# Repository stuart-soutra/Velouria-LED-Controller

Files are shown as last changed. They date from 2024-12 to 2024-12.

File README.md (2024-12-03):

# Velouria LED Controller
## Details
The Velouria LED Controller is a 30x20mm programmable, LED controller with battery charging and protection capabilities. 
Please feel free to build and use this board for your own projects.
## Driving NeoPixels
Ideal for driving small strings of NeoPixels, testing has shown that the DC/DC convertor on the board can power up to 12 individual NeoPixels at the same time (5V, 1A max. out of DC/DC Convertor); up to 16 may be achievable.
## MCU
The controller utilises an ATTiny412 MCU that can be programmed via. the UPDI programming header on the back of the board.
One output and one input are accesible via. solder pads on the bottom of the PCB (ideal for having one single input control a string of NeoPixels via. a data output from the MCU).
## Battery Charging/Protection
The battery charging/protection circuit accepts any 3.7V Li-Ion battery.
The controller allows charging from USB Micro B connector only.
The charging circuit outputs a safe charging current of 370mA - after initial testing, it was realised that this is a slow charging rate and will be changed for Rev B.
The battery protection circuit will automatically disconnect the battery from the circuit quickly in the event of over-charging or under-charging.
## New Battery Connection Procedure
If the protection circuit trips when a new battery is connected, please follow the steps below to ensure circuit reset after connection:
 - Connect Battery
 - Short GND to Bat Negative
 - Power cycle charger
## Current Rev (Uploaded)
Rev A
## Mods Required After Rev A Testing
After initial testing, the following mods will need to be implemented in Rev B - PLEASE ADD THESE YOURSELF IF YOU PLAN ON USING THE REV A VERSION:
- Use Diodes Inc. AP9101CK6-BJTRG1 instead of current protection IC - required footprint change
- Remove filter on Vcc at input to battery charger (remove R16 and C5) - short '+5V_FUSED' to 'CHARGE_VCC'
- Change R20 for higher charge current

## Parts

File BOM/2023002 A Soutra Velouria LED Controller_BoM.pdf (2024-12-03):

# Bill of Materials for Project [2023002 A Soutra Velouria LED Controller PROJ.PrjPcb]

Source Data From: | 2023002 A Soutra Velouria LED Controller PROJ.PrjPcb
Variant: | None
Report Date: | 29/11/2023 | 11:01
soutraelectronics@gmail.com

### 14 Ryehill Gardens

Edinburgh
EH68ER
+44(0)7874693650
Designator | Manufacturer Part Number | Value | Manufacturer | Footprint | Quantity | Notes | Supplier | Supplier Part Number | Pricing | Total Cost | Supplier 1 | Supplier Part Number 1 | Pricing 1 | Total Cost | Alternative Part | Alternative Part Manufacturer | Alternative Part Supplier | Alternative Part Supplier Part Number
C1, C5, C6, C7, C8, C9 | CC0402KRX5R6BB105 | 1uF | Yageo | CAPC1005X06L | 6 | Farnell | 1458896 | 10=0.039, 100=0.023 | 0.39 | Digikey | 311-1439-1-ND | 1=0.08, 10=0.058, 50=0.034, 100=0.027 | 0.48 | 0402ZD105KAT2A | KYOCERA AVX | Farnell | 1740588 | USE JLC STOCKED PART IF AVAILABLE
C2 | GRM21BR61A476ME15K | 47uF | Murata | CAPC2012X14L | 1 | Farnell | 3790438 | 10=0.276, 100=0.207 | 2.76 | Digikey | 490-GRM21BR61A476ME15KCT-ND | 1=0.53, 10=0.353, 50=0.28, 100=0.232 | 0.53 | C2012X5R1A476M125AC | TDK | Farnell | 2211186 | USE JLC STOCKED PART IF AVAILABLE
C3 | CL31A476MQHNNNE | 47uF | Samsung | CC1206-IPC_C | 1 | Farnell | 3013519 | New Product - Undefined Lead Time | 0 | Digikey | 1276-1167-1-ND | 1=0.24, 10=0.16, 50=0.118, 100=0.096 | 0.24 | C1206C476M9PACTU | KEMET | Farnell | 1650902 | USE JLC STOCKED PART IF AVAILABLE
C4 | 0402X104M160CT | 100nF | Walsin Technologies | CAPC1005X06L | 1 | Farnell | 2524808 | 10=0.0047, 100=0.0043 | 0.047 | Digikey | 1292-0402X104M160CT-ND | 1=0.08, 10=0.023, 50=0.013, 100=0.01 | 0.08 | 885012105016 | WURTH | Farnell | 2533933 | USE JLC STOCKED PART IF AVAILABLE
C10 | CC0603KPX7R9BB472 | 4.7nF | Yageo | CC0603-DA-IPC_C | 1 | Farnell | 3764512 | 10=0.024, 100=0.014 | 0.24 | Digikey | 13-CC0603KPX7R9BB472CT-ND | 1=0.08, 10=0.036, 50=0.02, 100=0.016 | 0.08 | MC0603B472K500CT | Multicomp Pro | Farnell | 1759098 | USE JLC STOCKED PART IF AVAILABLE
D1, D3 | NSR0530HT1G | ON Semiconductor | SODFL_250X100-2L | 2 | Farnell | 2508350 | 5=0.159, 10=0.117, 100=0.0654 | 0.795 | Digikey | NSR0530HT1GOSCT-ND | 1=0.16, 10=0.11, 100=0.059 | 0.32 | PMEG3010BEA,115 | NEXPERIA | Farnell | 8737991 | USE JLC STOCKED PART IF AVAILABLE
D2 | ESDA8V2-1J | STMicroelectronics | SODFL_250X117-2L | 1 | Farnell | 2353667 | 5=0.0848, 10=0.0807, 100=0.0765 | 0.424 | Rs | 9172719 | 100=0.148 | 14.8 | USE JLC STOCKED PART IF AVAILABLE
D4 | SS12L | Multicomp Pro | SODFL370X120-2L | 1 | Farnell | 3883703 | 5=0.089, 10=0.071, 100=0.051 | 0.445 | RSX101MM-30TR | Rohm | Farnell | 3214737 | USE JLC STOCKED PART IF AVAILABLE
D5 | MP008282 | Multicomp | DIOC_0603_1706X06L | 1 | Farnell | 3796313 | 5=0.0713, 10=0.0611, 100=0.0476 | 0.3565 | LG Q396-PS-35 | AMS OSRAM GROUP | Farnell | 2575345 | USE JLC STOCKED PART IF AVAILABLE
F1 | MCCFB0603TFF/1 | Multicomp | FUSC_1608X06L | 1 | Farnell | 2849996 | 1=0.027 (GBP) | 0.027 | MP001585 | Multicomp Pro | Farnell | 3285087 | USE JLC STOCKED PART IF AVAILABLE
J1 | 105017-0001 | Molex | 1050170001_USB-MICRO-B_V | 1 | Farnell | 3500663 | 1=0.97 | 0.97 | Rs | 8486764 | 5=0.754, 75=0.67 | 3.77 | USE JLC STOCKED PART IF AVAILABLE
J2 | N/A | SMT-PAD_2x3_1-27_R0-5 | 1 | No part - solder pad only | 0
J3 | N/A | SMT-PAD_2-Pad_2X5Y2-5P | 1 | No part - solder pad only | 0
J4 | N/A | SMT-PAD_3-Pad_5X8Y6P | 1 | No part - solder pad only | 0
L1 | SRP4020TA-3R3M | Bourns | SRP4020TA-MFG | 1 | Farnell | 2434803 | 5=0.543, 50=0.52 | 2.715 | Digikey | SRP4020TA-3R3MCT-ND | 1=1.04, 10=0.879, 25=0.799, 50=0.75, 100=0.623 | 1.04 | USE JLC STOCKED PART IF AVAILABLE
Q1 | XP161A1355PR-G | Torex | SOT89-150P350X160-3L | 1 | Farnell | 3534778 | 1=0.472, 10=0.413, 100=0.294 | 0.472 | Mouser | 865-XP161A1355PR-G | 1=0.568, 10=0.453, 100=0.353 | USE JLC STOCKED PART IF AVAILABLE
Q2, Q3 | RTQ020N05FRATR | Rohm | SOT457T_95P280X100-6L | 2 | Farnell | 2769553 | 5=0.359, 10=0.286, 100=0.2 | 1.795 | RTQ020N05HZGTR | Rohm | Farnell | 3261754 | USE JLC STOCKED PART IF AVAILABLE
R1, R9, R10, R22, R26 | MC0063W06030R | 0R | Multicomp | RESC_0603_1608X06L | 5 | Farnell | 9331662 | 10=0.007, 100=0.006 | 0.07 | MCWR06X000 PTL | Multicomp Pro | Farnell | 2447743 | USE JLC STOCKED PART IF AVAILABLE
R2, R16, R23, R24, R25, R27, R28RK73B1JTTD103J | 10kR | KOA Speer | RESC_0603_1608X06L | 7 | Farnell | 4009056 | 10=0.009, 100=0.003 | 0.09 | Digikey | 2019-RK73B1JTTD103JCT-ND | 1=0.08, 10=0.012, 50=0.0078, 100=0.0064 | 0.56 | RMCF0603FT10K0 | Stackpole Electronics Inc | Digikey | RMCF0603FT10K0CT-ND | USE JLC STOCKED PART IF AVAILABLE
R11 | CRCW0805100RFKTA | 100R | Vishay Dale | RESC_0805_2013X50X30LL20T20 | 1 | Farnell | 1652906 | 10=0.06, 100=0.026 | 0.6 | Mouser | 71-CRCW0805-100 | 1=0.12, 10=0.042, 100=0.027 | 0.12 | CRCW0805100RFKEA | VISHAY | Farnell | 1469862 | USE JLC STOCKED PART IF AVAILABLE
R12 | MCWR06X3091FTL | 3.09k | Multicomp | RESC_0603_1608X06L | 1 | Farnell | 2694817 | 10=0.011, 100=0.004 | 0.11 | RK73H1JTTD3091F | KOA | Farnell | 3539881 | USE JLC STOCKED PART IF AVAILABLE
R13 | CR0603-FX-4992ELF | 49.9kR | Bourns | RESC_0603_1608X06L | 1 | Farnell | 4014374 | 1=0.0871, 25=0.0148, 50=0.0105, 100=0.0061 | 0.0871 | Digikey | 118-CR0603-FX-4992ELFCT-ND | 1=0.08, 10=0.012, 50=0.007, 100=0.006 | 0.08 | USE JLC STOCKED PART IF AVAILABLE
R14 | RK73H1JRTTD1001F | 1kR | KOA Speer | RESC_0603_1608X06L | 1 | Farnell | 3539564 | 10=0.053, 100=0.02 | 0.53 | Digikey | 2019-RK73H1JRTTD1001FCT-ND | 1=0.11, 10=0.052, 50=0.034, 100=0.0288 | 0.11 | ERJUP3J102V | PANASONIC | Farnell | 3579508 | USE JLC STOCKED PART IF AVAILABLE
R15 | CRM0805AJX-R100ELF | R100 | Bourns | RESC_0805_2013X50X30LL20T20 | 1 | Farnell | 2824733 | 10=0.218, 100=0.168 | 2.18 | Digi-Key | CRM0805AJX-R100ELFCT-ND | 1=0.49, 10=0.277, 50=0.1988, 100=0.174 | 0.49 | ERJ6BSFR10V | PANASONIC | Farnell | 1717812 | USE JLC STOCKED PART IF AVAILABLE
R17 | CRGH0805J330R | 330R | TE Connectivity | RESC_0805_2013X50X30LL20T20 | 1 | Farnell | 2331789 | 10=0.012 | 0.12 | Rs | 8075778P | 1000=0.012 | 12 | USE JLC STOCKED PART IF AVAILABLE
R18 | RC0603FR-07150RL | 150R | Yageo | RESC_0603_1608X06L | 1 | Farnell | 9238387 | 10=0.011, 100=0.006 | 0.11 | Digikey | 311-150HRCT-ND | 1=0.08, 10=0.016, 50=0.009, 100=0.008 | 0.08 | MCWR06X1500FTL | Multicomp Pro | Farnell | 2447255 | USE JLC STOCKED PART IF AVAILABLE
R19 | CRGH0805F2K7 | 2.7k | TE Connectivity | RESC_0805_2013X50X30LL20T20 | 1 | Farnell | 2332077 | 10=0.0381 | 0.381 | Mouser | 279-CRGH0805F2K7 | 1=0.096, 10=0.065, 100=0.033 | 0.096 | MC01W08051100R | Multicomp Pro | Farnell | 9332375 | USE JLC STOCKED PART IF AVAILABLE
R20 | RC0402FR-072K7L | 2.7kR | Yageo | RESC_0402_1005X40X25LL05T10 | 1 | Farnell | 9239286 | 10=0.008, 100=0.005 | 0.08 | Digikey | 311-2.70KLRCT-ND | 1=0.08, 10=0.012, 50=0.007, 100=0.006 | 0.08 | MCSR04X2701FTL | Multicomp Pro | Farnell | 2074044 | USE JLC STOCKED PART IF AVAILABLE
SW1 | N/A | SMT-PAD_2-Pad_2X5Y2-5P | 1 | No part - solder pad only | 0
U1 | ATTINY412-SSNR | Microchip | SOIC127P600X200-8L | 1 | Farnell | 3131843 | 1=0.469, 25=0.429, 100=0.39 | 0.469 | Digikey | ATTINY412-SSNRCT-ND | 1=0.48, 25=0.437, 0.388 | 0.48 | USE JLC STOCKED PART IF AVAILABLE
U2 | MCP1650S-E/MS | Microchip | MSOP-MS8_L | 1 | Farnell | 1863920 | 1=1.548 | 1.548 | Digikey | MCP1650S-E/MS-ND | 1=1.54, 25=1.288, 100=1.228 | 1.54 | USE JLC STOCKED PART IF AVAILABLE
U3 | LTC4065EDC#TRMPBF | Analog Devices / Linear Technology | DFN_0P200X200X85_HS-7L | 1 | Farnell | 4027894 | 1=3.14, 10=2.81, 25=2.67, 100=2.31 | 3.14 | Digikey | 505-LTC4065EDC#TRMPBFCT-ND | 1=2.94, 10=2.64, 25=2.495, 100=2.162 | 2.94 | USE JLC STOCKED PART IF AVAILABLE
U4 | AP9101CK-AHTRG1 | Diodes | SOT25_95P285X140-5L | 1 | Farnell | 3483011 | 5=0.318, 10=0.231, 100=0.165 | 1.59 | DigiKey | AP9101CK-AHTRG1DICT-ND | 1=0.36, 10=0.28, 100=0.169 | 0.36 | USE JLC STOCKED PART IF AVAILABLE
U5 | AP22802AW5-7 | Diodes | SOT25_95P285X140-5L | 1 | Farnell | 3482850 | 5=0.152, 10=0.133, 100=0.11 | 0.76 | Digikey | AP22802AW5-7DICT-ND | 1=0.37, 10=0.277, 25=0.25, 100=0.173 | 0.37 | USE JLC STOCKED PART IF AVAILABLE
U6 | AP331AWRG-7 | Diodes | SOT25_95P285X140-5L | 1 | Farnell | 3373792 | 5=0.259, 10=0.16, 100=0.098 | 1.295 | Digikey | AP331AWRGDICT-ND | 1=0.38, 10=0.28, 25=0.256, 100=0.176 | 0.38 | USE JLC STOCKED PART IF AVAILABLE
Note: | - All prices in GBP | Total Number of Items: | 52

TOTAL MAX COST PER BOARD
(Primary Supplier Only): | 24.5966
- Supplier minimum order amount assumed if number of components is less
- PLEASE CHOOSE CHEAPEST AVAILABLE COMPONENT CHOICE WHEN SOURCING
Primary Supplier | Secondary Supplier | Alternative Part Details | JLC Stock Accepted?

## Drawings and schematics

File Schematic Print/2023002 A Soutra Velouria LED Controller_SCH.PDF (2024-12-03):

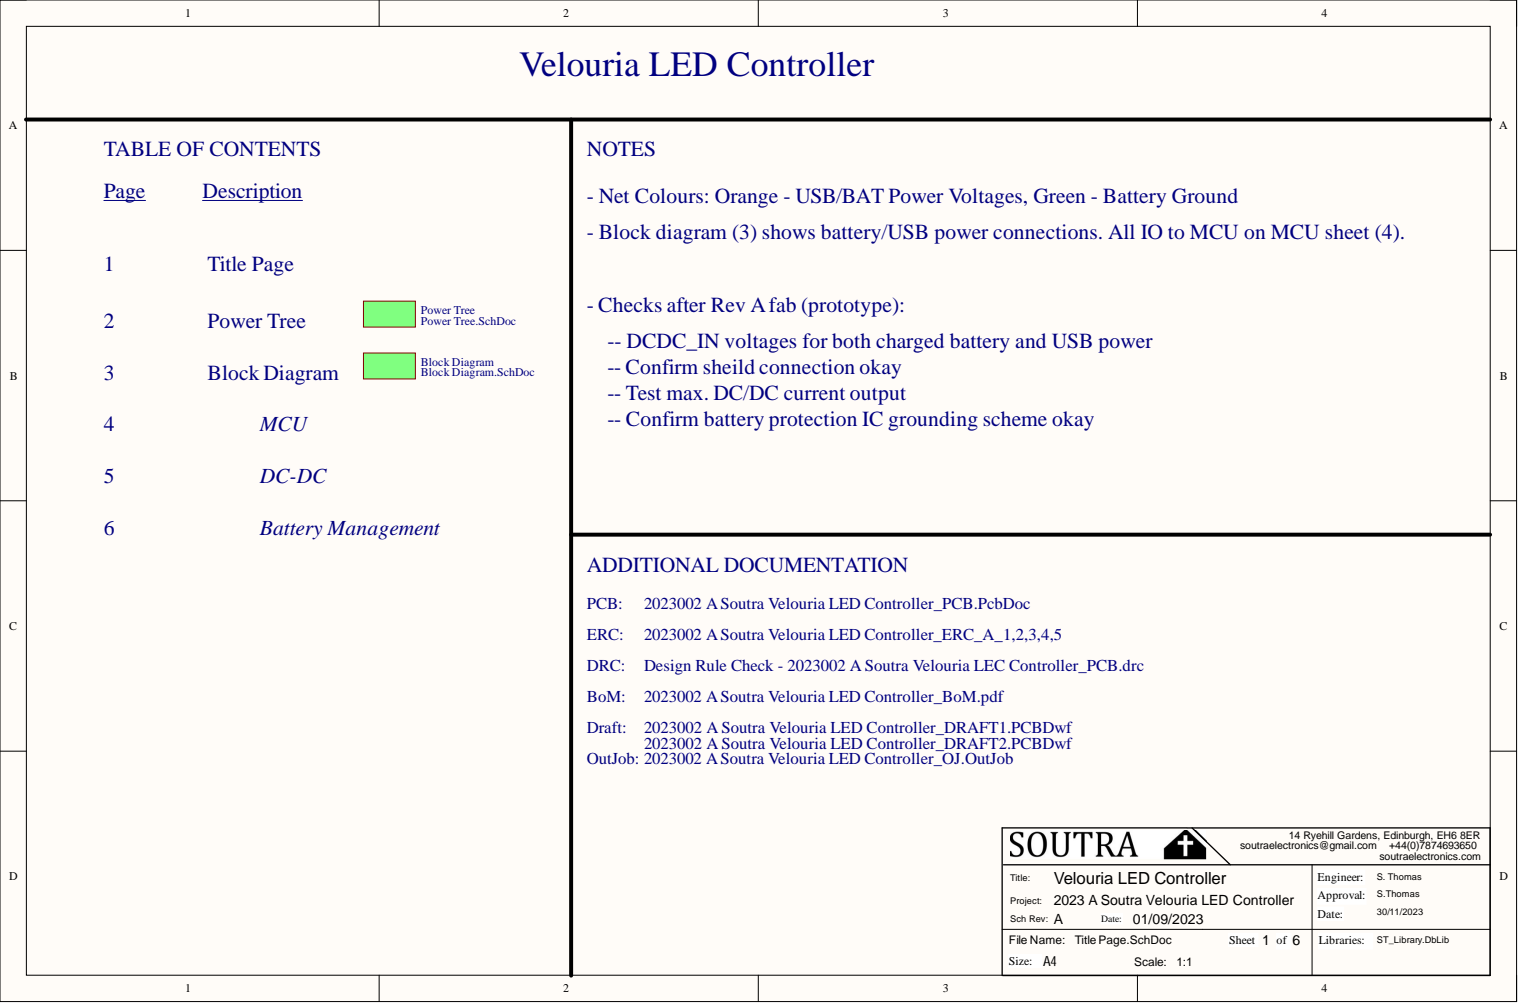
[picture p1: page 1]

- Net Colours: Orange - USB/BAT Power Voltages, Green - Battery Ground
- Block diagram (3) shows battery/USB power connections. All IO to MCU on MCU sheet (4).

- Checks after Rev Afab (prototype):
-- DCDC_IN voltages for both charged battery and USB power
-- Confirm sheild connection okay
-- Test max. DC/DC current output
-- Confirm battery protection IC grounding scheme okay

Power Tree Power Tree.SchDoc

Block Diagram Block Diagram.SchDoc

Design Rule Check - 2023002 A Soutra Velouria LEC Controller_PCB.drc

2023002 A Soutra Velouria LED Controller_BoM.pdf

2023002 A Soutra Velouria LED Controller_DRAFT1.PCBDwf
2023002 A Soutra Velouria LED Controller_DRAFT2.PCBDwf
2023002 A Soutra Velouria LED Controller_OJ.OutJob

Velouria LED Controller
2023 A Soutra Velouria LED Controller

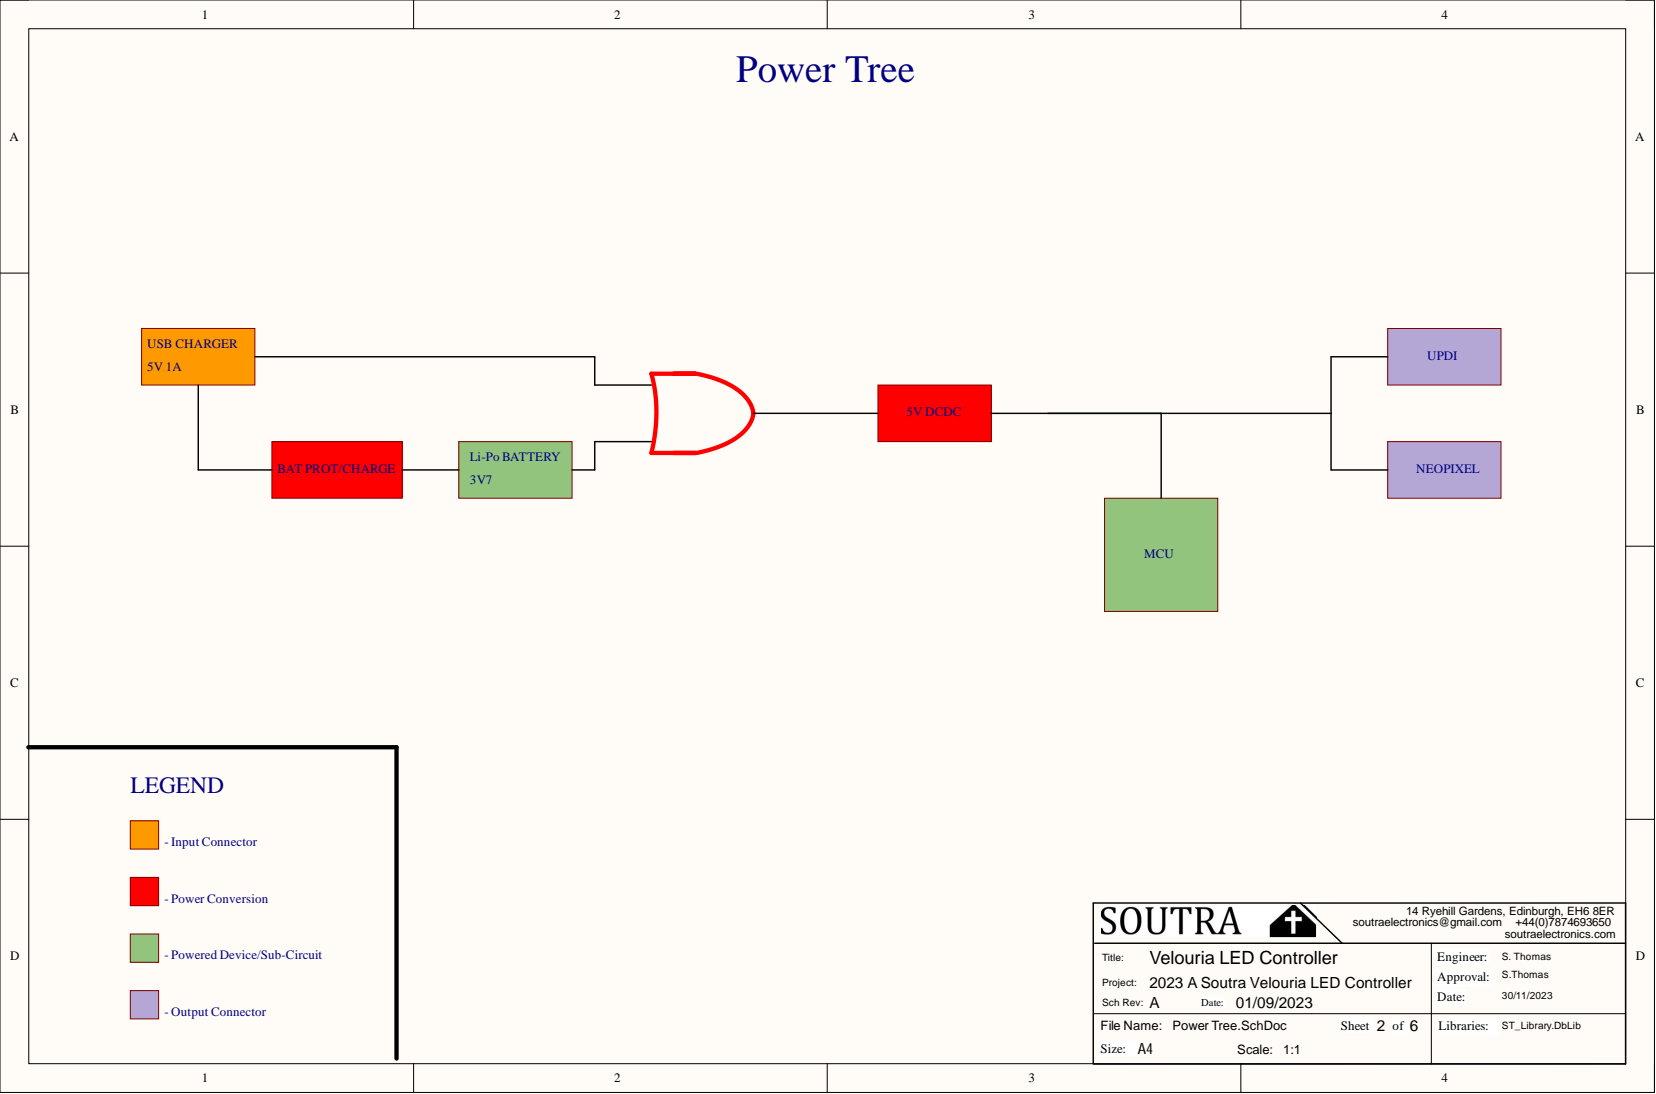
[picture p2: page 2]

- Powered Device/Sub-Circuit

Velouria LED Controller
2023 A Soutra Velouria LED Controller

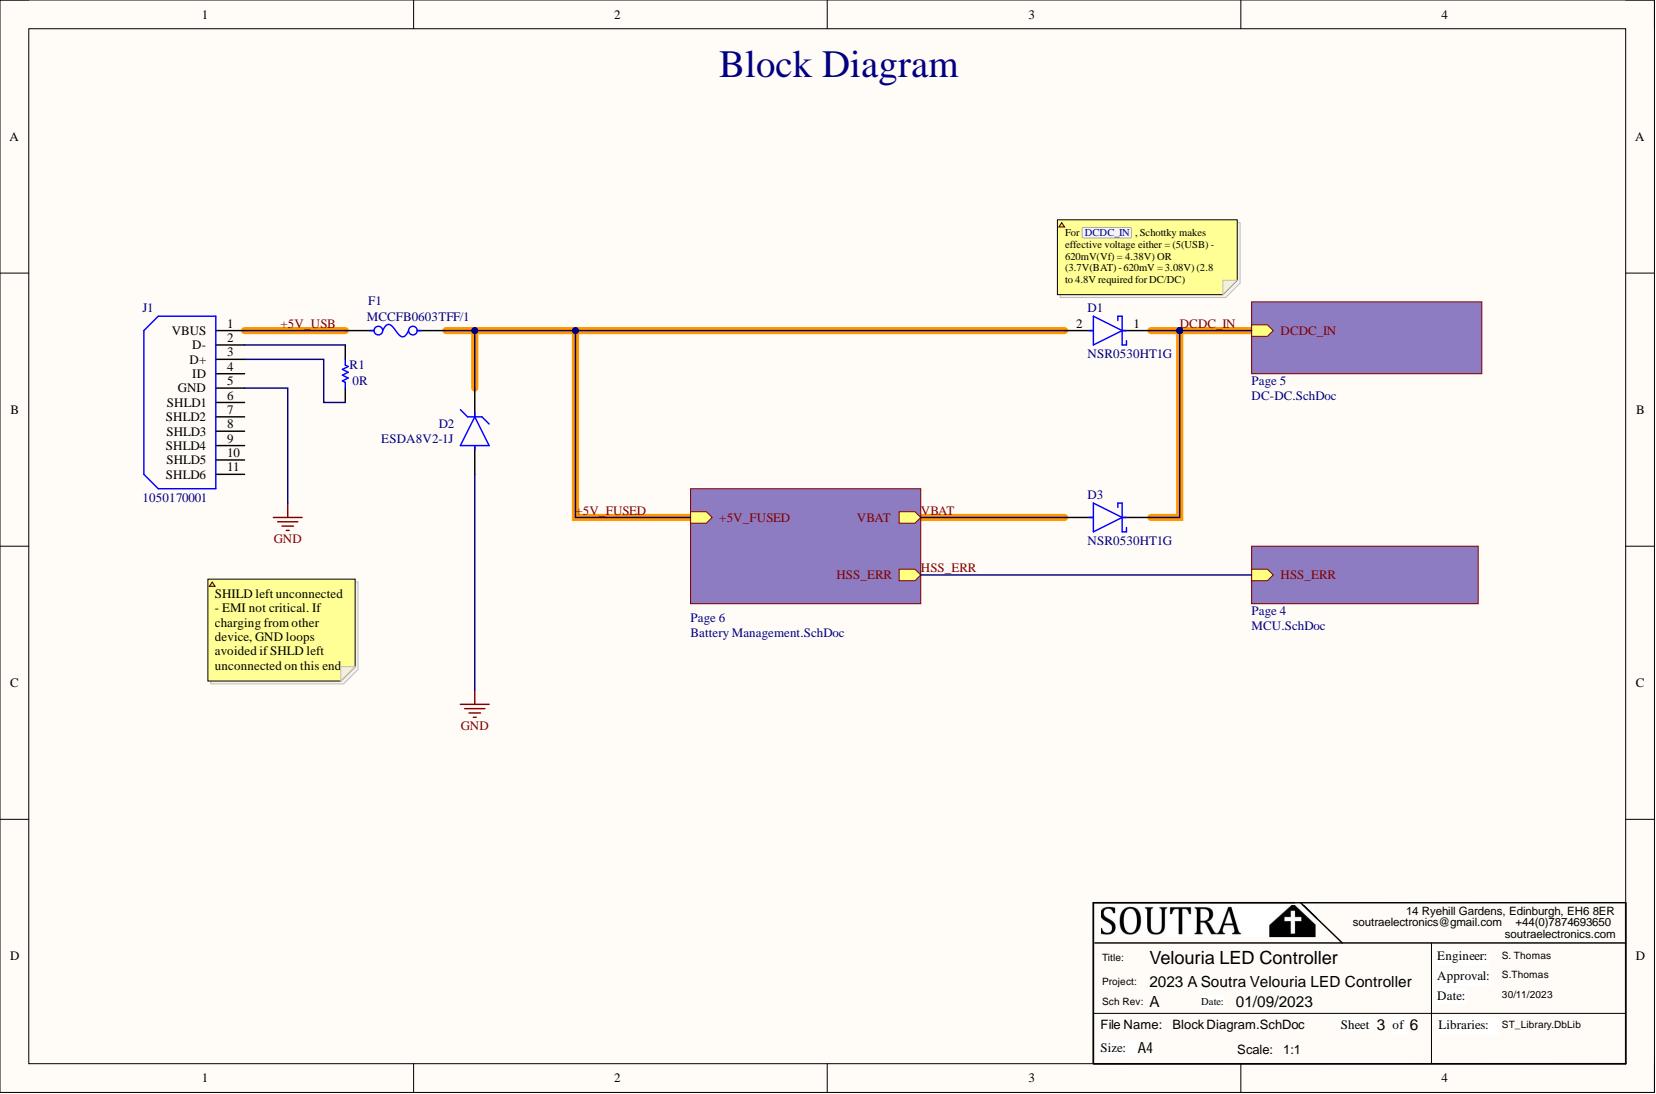
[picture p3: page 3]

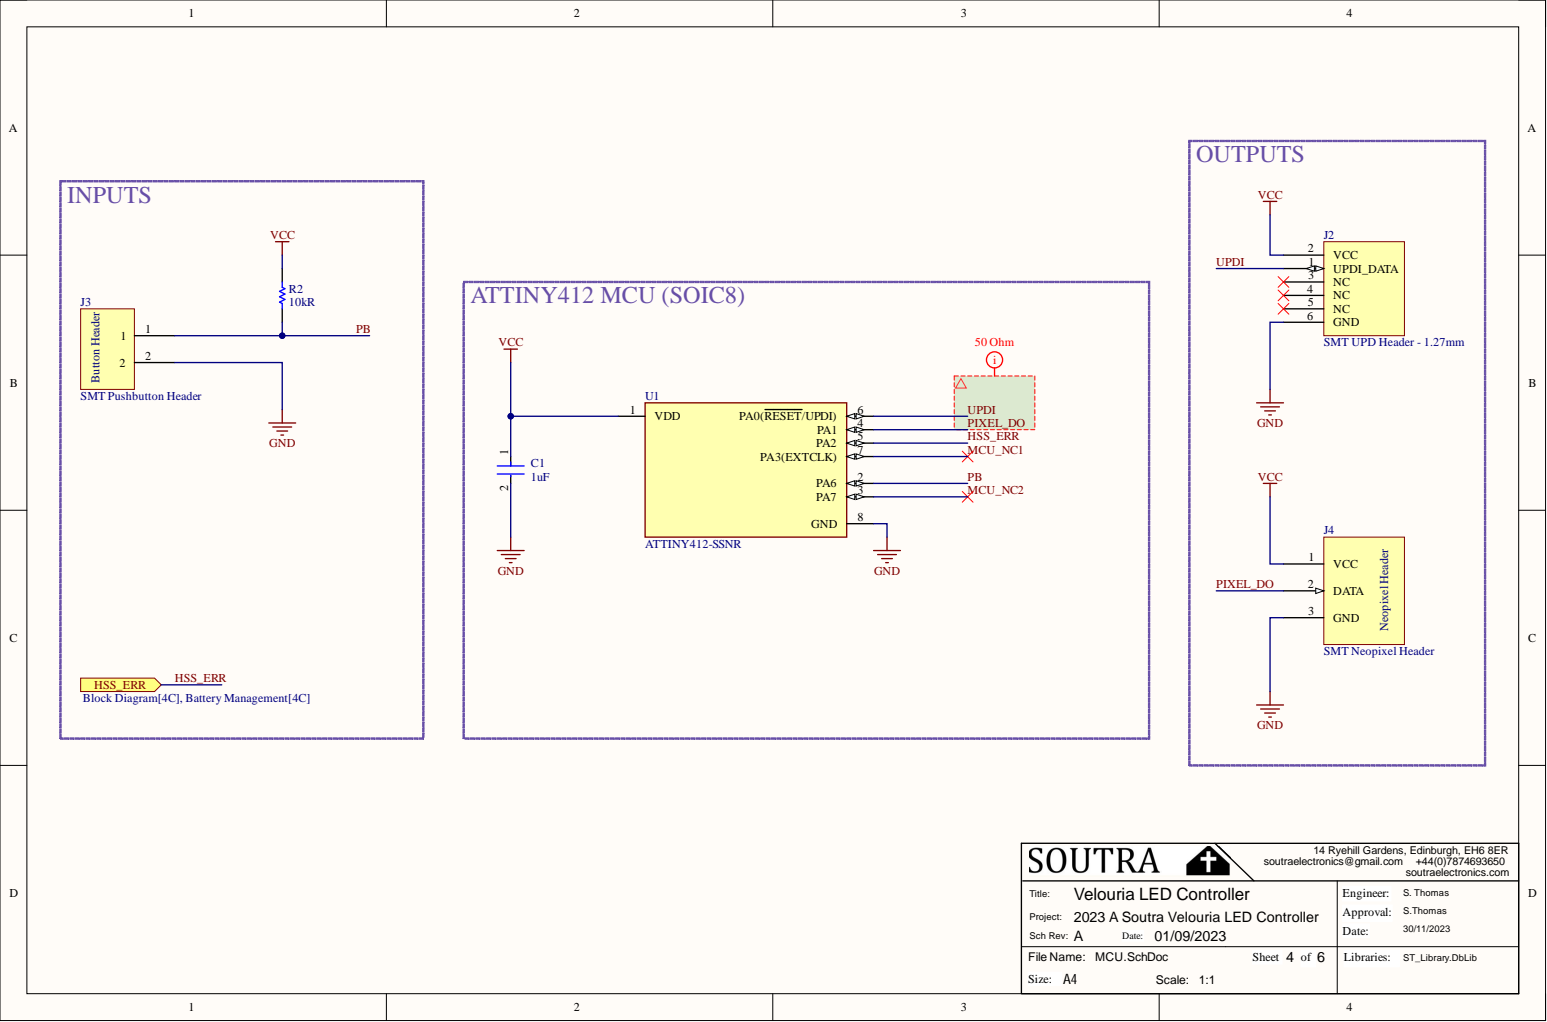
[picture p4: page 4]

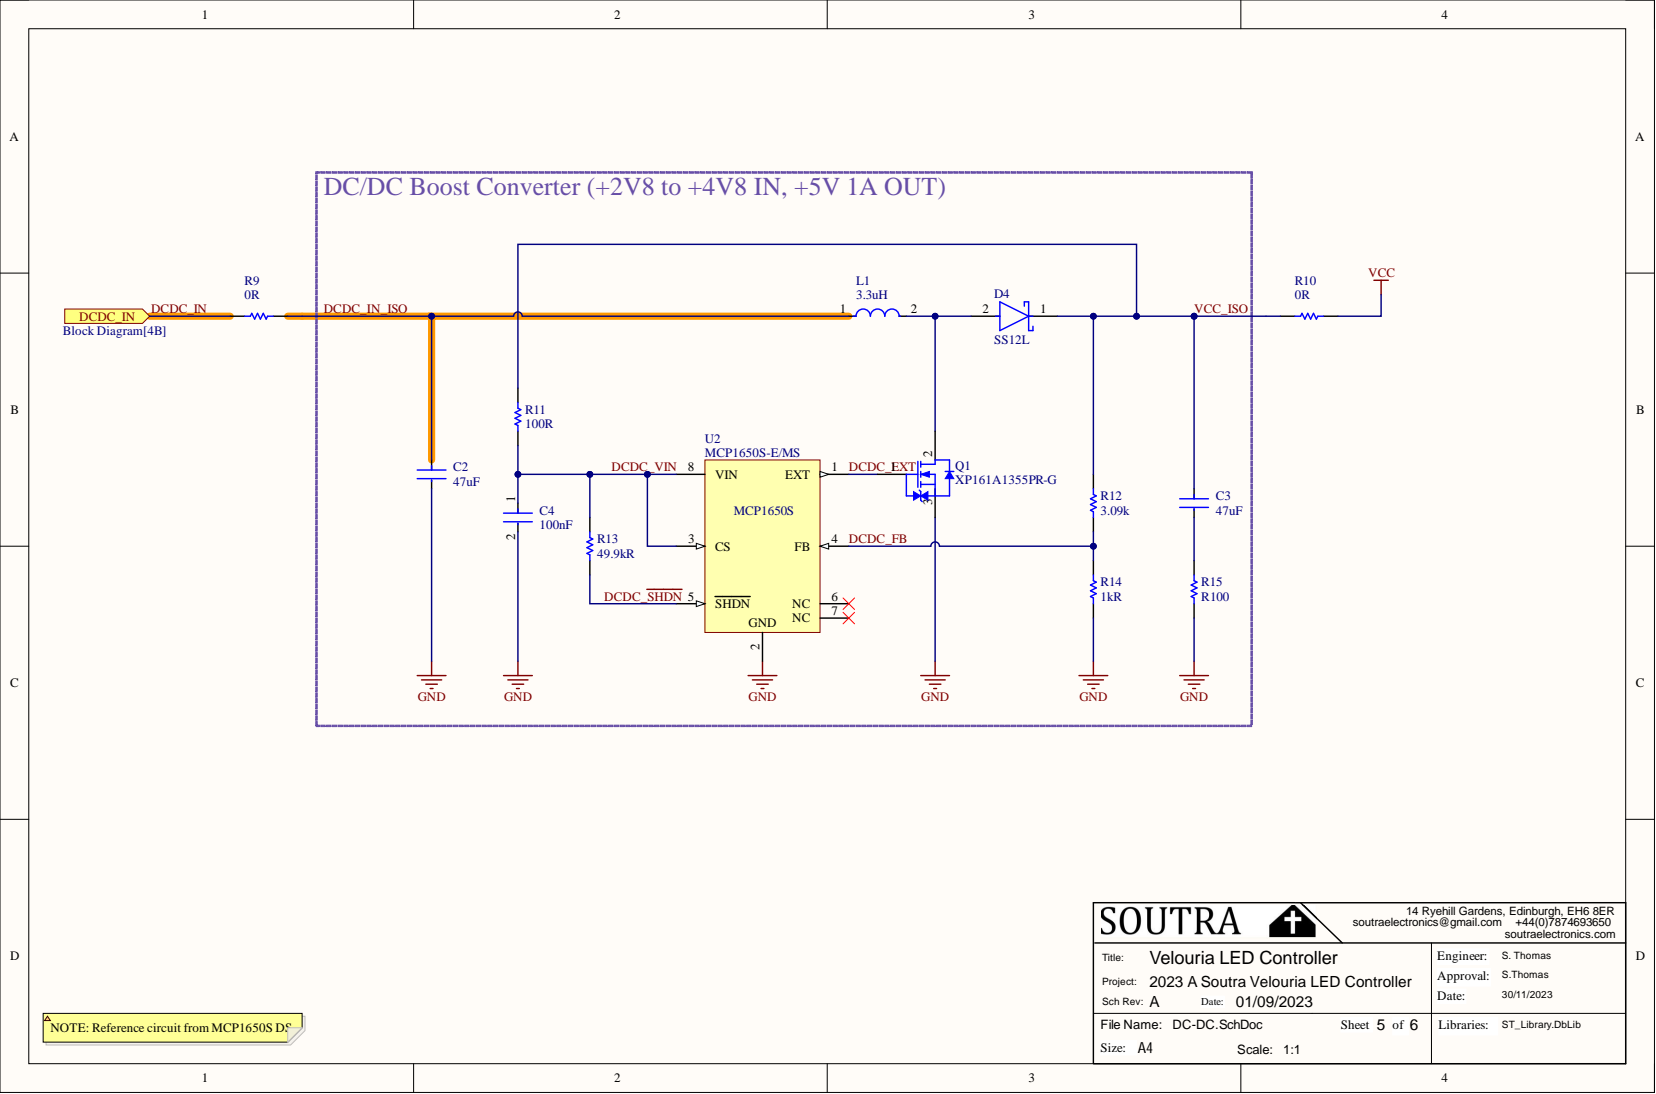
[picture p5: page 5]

DC/DC Boost Converter (+2V8 to +4V8 IN, +5V 1A OUT)

V IN 8 | V IN E X T MCP1 6 5 0 S CS FB SH D N N C N C G N D | 1

3 | 4 DCDC_ FB

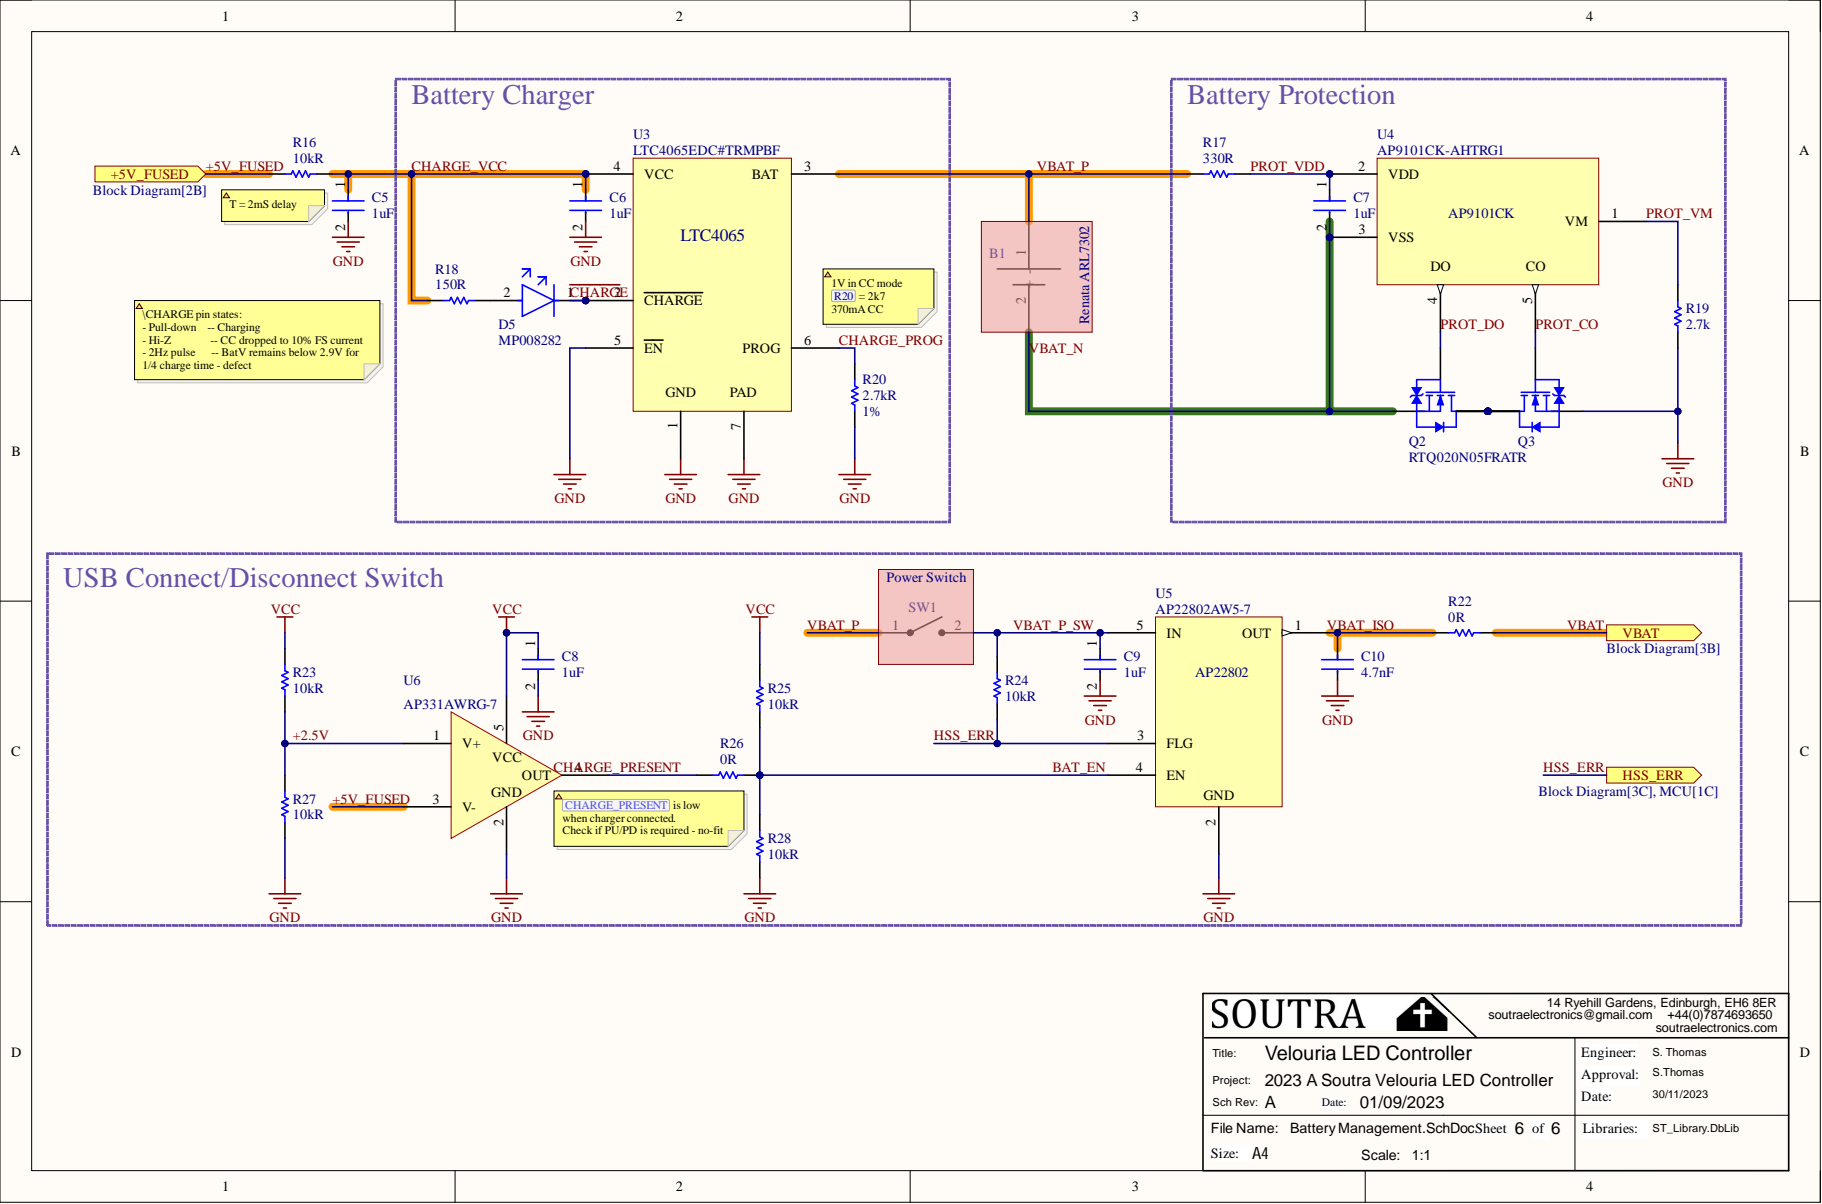
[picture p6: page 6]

USB Connect/Disconnect Switch

CHARGE_PRESENT islow
when charger connected.
Check if PU/PD is required - no-fit

Velouria LED Controller
2023 A Soutra Velouria LED Controller
